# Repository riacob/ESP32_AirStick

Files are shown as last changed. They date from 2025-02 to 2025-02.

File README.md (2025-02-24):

# ESP32 AirStick
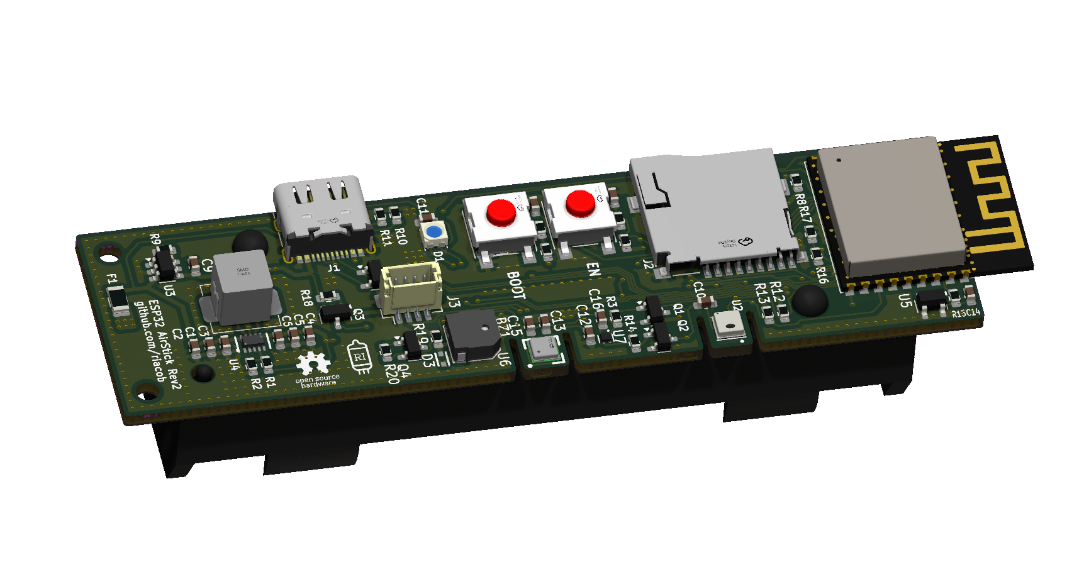
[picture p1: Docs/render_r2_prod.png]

The board is currently in Rev2

## Features
- AHT20 Temperature & Humidity Sensor
- ENS160 eCO2, AQI, TVOCs Sensor
- Measured TVOCs and their range:
  - Ethanol 0-6 ppm
  - Hydrogen 0-10 ppm
  - Acetone 0-32 ppm
  - Carbon Monoxide 0-90 ppm
  - Toluene 0-32 ppm
- 18650 Li-ion battery holder, TP4057 charging circuitry
- Battery protection with fuse and DW03
- USB Type-C with USB CDC for emulated UART and charging, ESD protected
- MicroSD TF card slot for data logging
- ESP32C3 For WiFi and BLE connectivity
- Still work in progress, compatible with [BLEMQTTPair]() app
- WS2812B led for indication and alarm
- Optional SSD1306 OLED 
- 75dB magnetic buzzer for alarm
- SparkFun Qwiic connector, in JST-SH 1.0mm pitch connector
- Optional connector to bring the rst and boot buttons to a remote front panel
- Low power, long life, high efficiency circuitry for optimized battery use
- Low BOM cost, consolidated parts, robust layout

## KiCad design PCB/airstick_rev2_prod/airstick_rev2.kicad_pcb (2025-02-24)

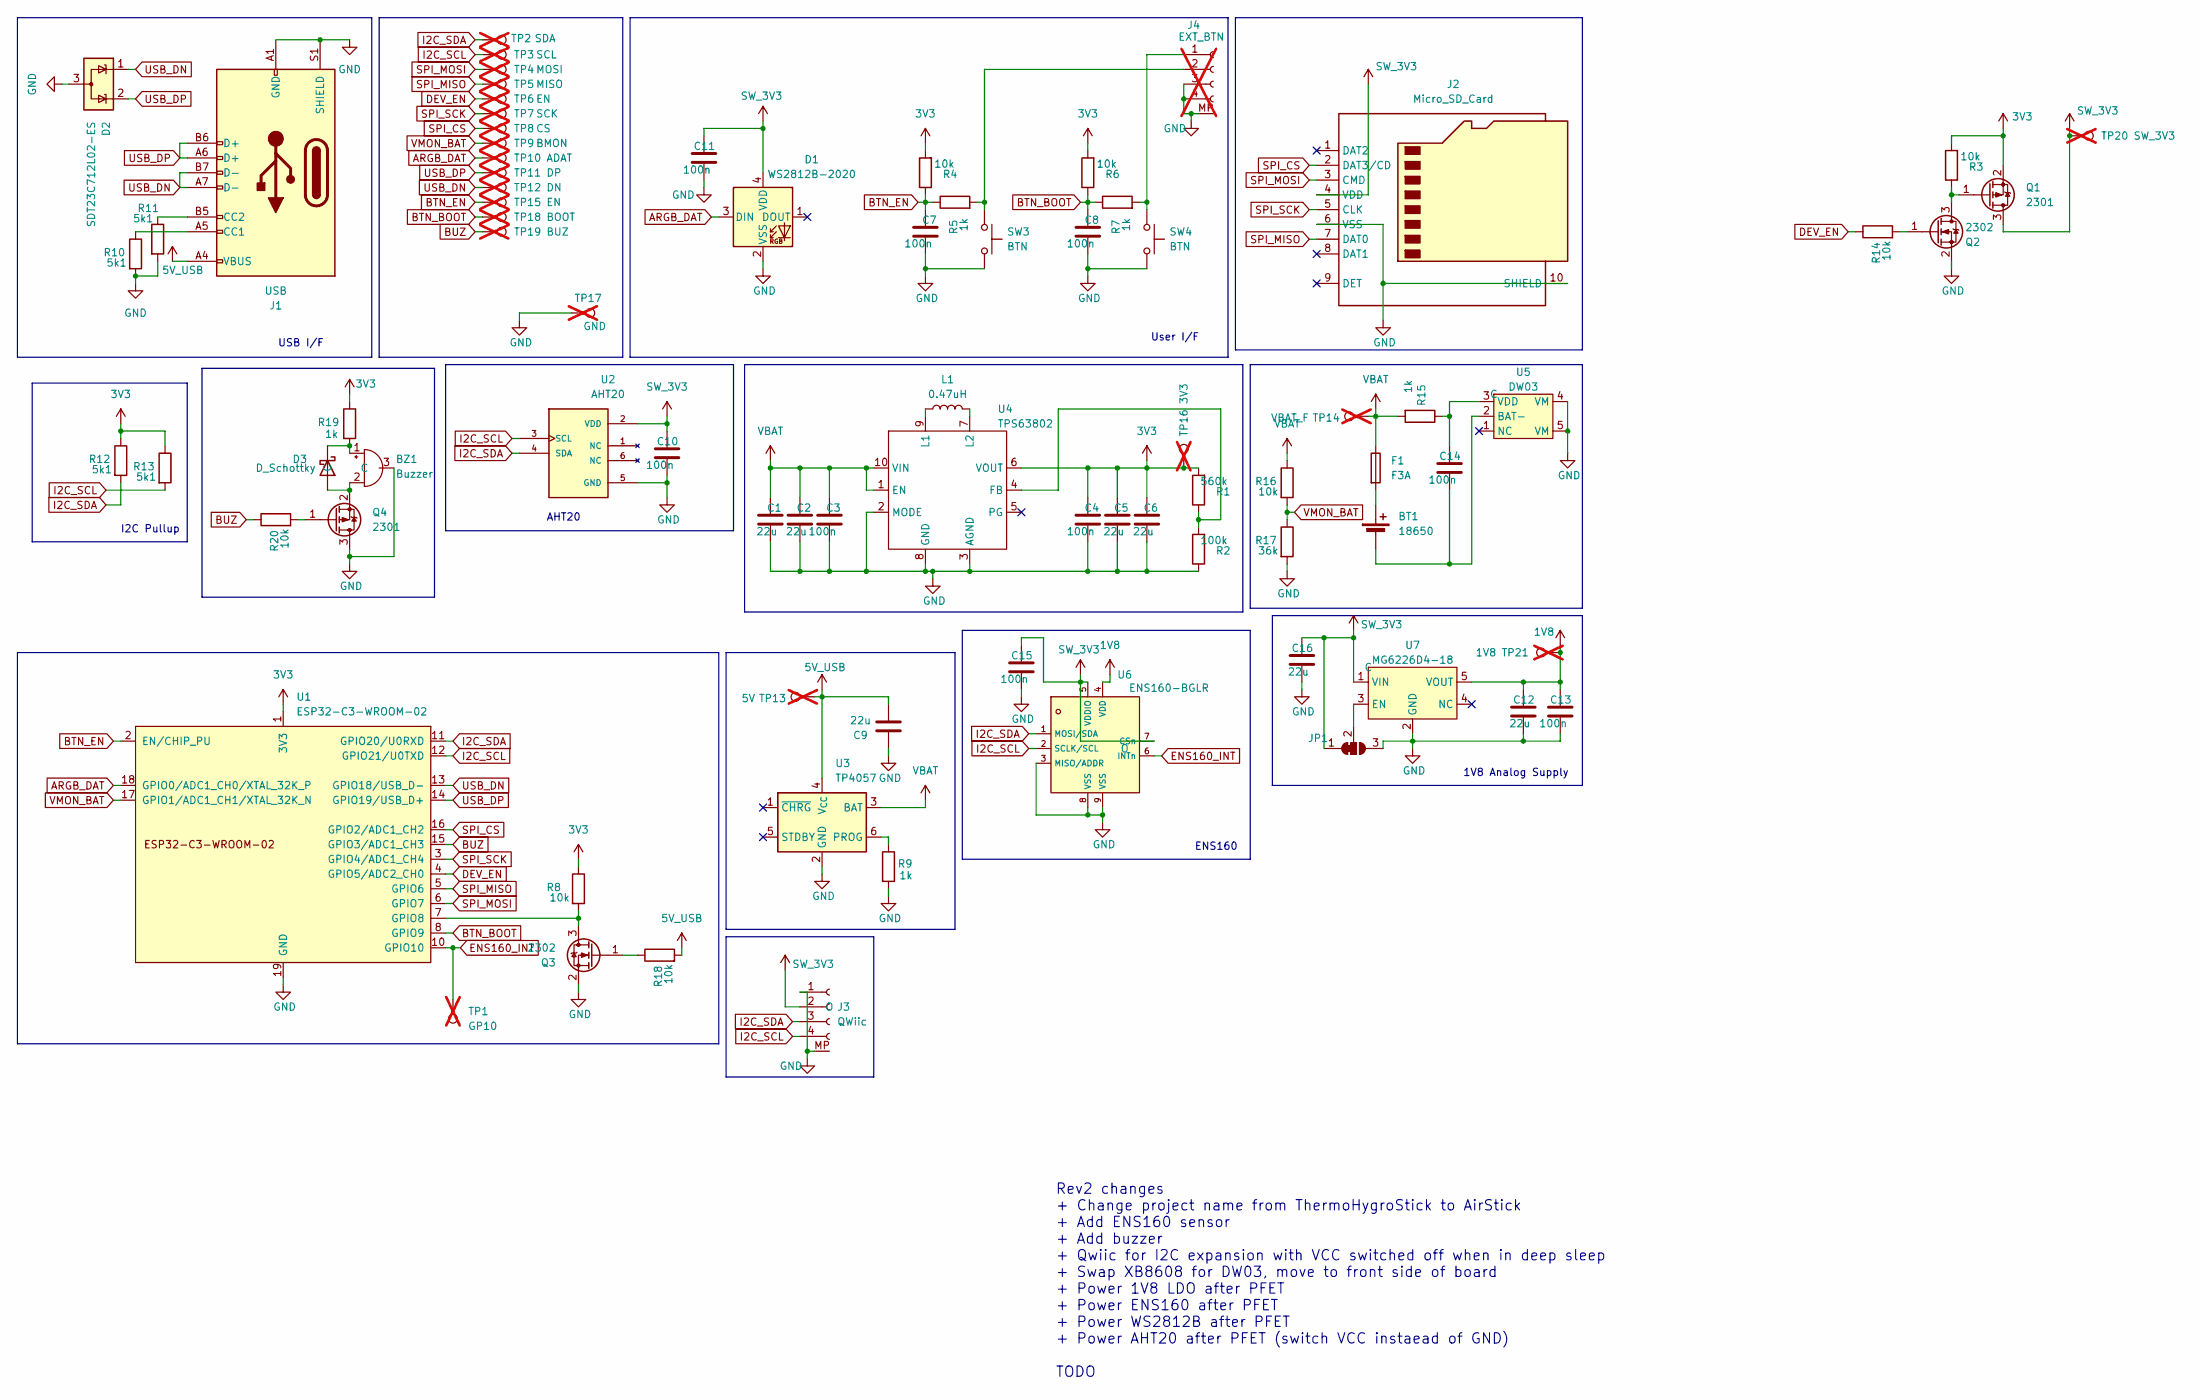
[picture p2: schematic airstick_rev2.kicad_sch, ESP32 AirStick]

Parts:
BT1: 18650; BatteryHolder_Keystone_1042_1x18650; LCSC C2988620
BZ1: Buzzer; BUZ-SMD_FST-5020; LCSC C391029
C1, C2, C5, C6, C9, C12, C16: 22u; C_0603_1608Metric; LCSC C159801
C3, C4, C7, C8, C10, C11, C13, C14, C15: 100n; C_0603_1608Metric; LCSC C1729
D1: WS2812B-2020; LED_WS2812B-2020_PLCC4_2.0x2.0mm; LCSC C5349955
D2: SDT23C712L02-ES; SOT-23-3; LCSC C5180269
D3: D_Schottky; SOD-723_L1.7-W1.0-P1.42-RD; LCSC C8525
F1: F3A; Fuse_1206_3216Metric; LCSC C163126
J1: USB; USB_C_Receptacle_G-Switch_GT-USB-7010ASV; LCSC C2988369
J2: Micro_SD_Card; J_SD_Card-micro_socket_A; LCSC C2988369
J3: QWiic; JST_SH_BM04B-SRSS-TB_1x04-1MP_P1.00mm_Vertical
J4: EXT_BTN; JST_SH_BM04B-SRSS-TB_1x04-1MP_P1.00mm_Vertical; not fitted
JP1: SolderJumper_3_Bridged12; SolderJumper-3_P1.3mm_Bridged12_RoundedPad1.0x1.5mm
L1: 0.47uH; L_SMD_7.1x6.6mm; LCSC C22463816
Q1, Q4: 2301; SOT-23; LCSC C41384537
Q2, Q3: 2302; SOT-23; LCSC C41384540
R1: 560k; R_0603_1608Metric; LCSC C17414
R2: 100k; R_0603_1608Metric; LCSC C17414
R3, R4, R6, R8, R14, R16, R18, R20: 10k; R_0603_1608Metric; LCSC C17414
R5, R7, R9, R15, R19: 1k; R_0603_1608Metric; LCSC C17414
R10, R11, R12, R13: 5k1; R_0603_1608Metric; LCSC C17414
R17: 36k; R_0603_1608Metric; LCSC C17414
SW3, SW4: BTN; SW_Push_1P1T_NO_6x6mm_H9.5mm; LCSC C2888455
TP1: GP10; TestPoint_Pad_D1.0mm_NoSilk; not fitted
TP2: SDA; TestPoint_Pad_D1.0mm_NoSilk; not fitted
TP3: SCL; TestPoint_Pad_D1.0mm_NoSilk; not fitted
TP4: MOSI; TestPoint_Pad_D1.0mm_NoSilk; not fitted
TP5: MISO; TestPoint_Pad_D1.0mm_NoSilk; not fitted
TP6, TP15: EN; TestPoint_Pad_D1.0mm_NoSilk; not fitted
TP7: SCK; TestPoint_Pad_D1.0mm_NoSilk; not fitted
TP8: CS; TestPoint_Pad_D1.0mm_NoSilk; not fitted
TP9: BMON; TestPoint_Pad_D1.0mm_NoSilk; not fitted
TP10: ADAT; TestPoint_Pad_D1.0mm_NoSilk; not fitted
TP11: DP; TestPoint_Pad_D1.0mm_NoSilk; not fitted
TP12: DN; TestPoint_Pad_D1.0mm_NoSilk; not fitted
TP13: 5V; TestPoint_Pad_D1.0mm_NoSilk; not fitted
TP14: VBAT_F; TestPoint_Pad_D1.0mm_NoSilk; not fitted
TP16: 3V3; TestPoint_Pad_D1.0mm_NoSilk; not fitted
TP17: GND; TestPoint_Pad_4.0x4.0mm; not fitted
TP18: BOOT; TestPoint_Pad_D1.0mm_NoSilk; not fitted
TP19: BUZ; TestPoint_Pad_D1.0mm_NoSilk; not fitted
TP20: SW_3V3; TestPoint_Pad_D1.0mm_NoSilk; not fitted
TP21: 1V8; TestPoint_Pad_D1.0mm_NoSilk; not fitted
U1: ESP32-C3-WROOM-02; LCSC C2934560
U2: AHT20; PSON100P300X300X110-6N; PARTREV V1.0; LCSC C2757850
U3: TP4057; SOT-23-6; LCSC C20199358
U4: TPS63802; DLA0010A; LCSC C1849531
U5: DW03; SOT-23-5
U6: ENS160-BGLR; LGA-9_L3.0-W3.0-R3-C3-P1.05-TL; LCSC C3659351
U7: MG6226D4-18; Texas_X2SON-4_1x1mm_P0.65mm; LCSC C22396246

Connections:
1V8: C12.1, C13.1, TP21.1, U6.4 (VDD), U7.5 (VOUT)
3V3: C4.1, C5.1, C6.1, Q1.2 (S), R1.2, R3.2, R4.2, R6.2, R8.1, R12.1, R13.1, R19.1, TP16.1, U1.1 (3V3), U4.6 (VOUT)
5V_USB: C9.2, J1.A4 (VBUS), J1.A9 (VBUS), J1.B4 (VBUS), J1.B9 (VBUS), R18.2, TP13.1, U3.4 (V_{CC})
ARGB_DAT: D1.3 (DIN), TP10.1, U1.18 (GPIO0/ADC1_CH0/XTAL_32K_P)
BTN_BOOT: C8.1, R6.1, R7.1, TP18.1, U1.8 (GPIO9)
BTN_EN: C7.1, R4.1, R5.1, TP15.1, U1.2 (EN/CHIP_PU)
BUZ: R20.1, TP19.1, U1.15 (GPIO3/ADC1_CH3)
DEV_EN: R14.1, TP6.1, U1.4 (GPIO5/ADC2_CH0)
ENS160_INT: TP1.1, U1.10 (GPIO10), U6.6 (INTn)
GND: BZ1.3 (-), C1.2, C2.2, C3.2, C4.2, C5.2, C6.2, C7.2, C8.2, C9.1, C10.2, C11.2, C12.2, C13.2, C15.2, C16.2, D1.2 (VSS), D2.3 (A), J1.A1 (GND), J1.A12 (GND), J1.B1 (GND), J1.B12 (GND), J1.S1 (SHIELD), J2.6 (VSS), J2.10 (SHIELD), J3.1, J3.MP, J4.3, J4.4, J4.MP, JP1.3 (B), Q2.2 (S), Q3.2 (S), Q4.3 (D), R2.1, R9.2, R10.2, R11.2, R17.2, SW3.2, SW4.2, TP17.1, U1.9 (GND), U1.19 (GND), U2.5 (GND), U3.2 (GND), U4.2 (MODE), U4.3 (AGND), U4.8 (GND), U5.4 (VM), U5.5 (VM), U6.3 (MISO/ADDR), U6.8 (VSS), U6.9 (VSS), U7.2 (GND)
I2C_SCL: J3.4, R13.2, TP3.1, U1.12 (GPIO21/U0TXD), U2.3 (SCL), U6.2 (SCLK/SCL)
I2C_SDA: J3.3, R12.2, TP2.1, U1.11 (GPIO20/U0RXD), U2.4 (SDA), U6.1 (MOSI/SDA)
unnamed: BT1.1 (+), F1.2
unnamed: BT1.2 (-), C14.2, U5.2 (BAT-)
unnamed: BZ1.1 (+), D3.1 (K), R19.2
unnamed: BZ1.2 (-), D3.2 (A), Q4.2 (S)
unnamed: J1.A5 (CC1), R10.1
unnamed: J1.B5 (CC2), R11.1
unnamed: J4.1, R7.2, SW4.1
unnamed: J4.2, R5.2, SW3.1
unnamed: JP1.2 (C), U7.3 (EN)
unnamed: Q1.1 (G), Q2.3 (D), R3.1
unnamed: Q2.1 (G), R14.2
unnamed: Q3.3 (D), R8.2, U1.7 (GPIO8)
unnamed: Q3.1 (G), R18.1
unnamed: Q4.1 (G), R20.2
unnamed: R9.1, U3.6 (PROG)
unnamed: R1.1, R2.2, U4.4 (FB)
unnamed: L1.1, U4.9 (L1)
unnamed: L1.2, U4.7 (L2)
unnamed: C14.1, R15.1, U5.3 (VDD)
SPI_CS: J2.2 (DAT3/CD), TP8.1, U1.16 (GPIO2/ADC1_CH2)
SPI_MISO: J2.7 (DAT0), TP5.1, U1.5 (GPIO6)
SPI_MOSI: J2.3 (CMD), TP4.1, U1.6 (GPIO7)
SPI_SCK: J2.5 (CLK), TP7.1, U1.3 (GPIO4/ADC1_CH4)
SW_3V3: C10.1, C11.1, C15.1, C16.1, D1.4 (VDD), J2.4 (VDD), J3.2, JP1.1 (A), Q1.3 (D), TP20.1, U2.2 (VDD), U6.5 (VDDIO), U6.7 (CSn), U7.1 (VIN)
USB_DN: D2.1 (K), J1.A7 (D-), J1.B7 (D-), TP12.1, U1.13 (GPIO18/USB_D-)
USB_DP: D2.2 (K), J1.A6 (D+), J1.B6 (D+), TP11.1, U1.14 (GPIO19/USB_D+)
VBAT: C1.1, C2.1, C3.1, F1.1, R15.2, R16.1, TP14.1, U3.3 (BAT), U4.1 (EN), U4.10 (VIN)
VMON_BAT: R16.2, R17.1, TP9.1, U1.17 (GPIO1/ADC1_CH1/XTAL_32K_N)

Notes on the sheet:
1V8 Analog Supply
Rev2 changes + Change project name from ThermoHygroStick to AirStick + Add ENS160 sensor + Add buzzer + Qwiic for I2C expansion with VCC switched off when in deep sleep + Swap XB8608 for DW03, move to front side of board + Power 1V8 LDO after PFET + Power ENS160 after PFET + Power WS2812B after PFE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
AHT20
I2C Pullup
USB I/F
User I/F
ENS160

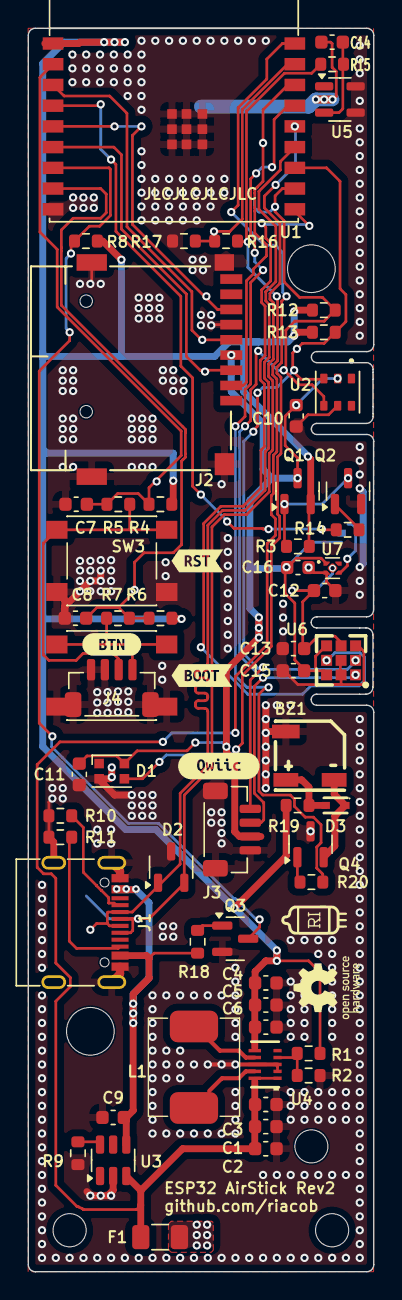
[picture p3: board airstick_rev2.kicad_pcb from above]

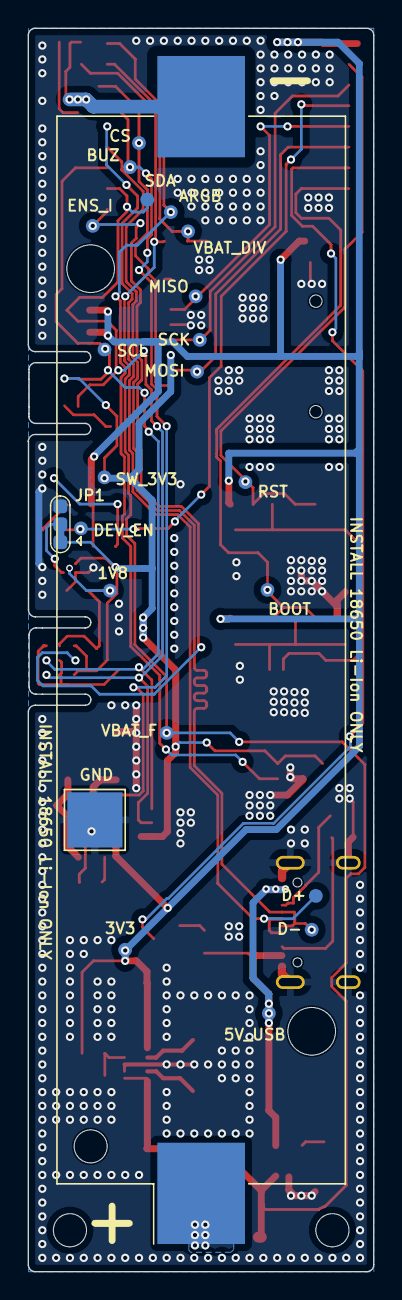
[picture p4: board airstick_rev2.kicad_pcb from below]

Board: 2 copper layers, 25.0 x 90.0 mm, 86 parts (23 on the bottom side), 40 nets.

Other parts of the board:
kibuzzard-67BA5A9B: G***; kibuzzard-67BA5A9B
kibuzzard-67BA57D8: G***; kibuzzard-67BA57D8
kibuzzard-67BA587D: G***; kibuzzard-67BA587D
kibuzzard-67BA5873: G***; kibuzzard-67BA5873

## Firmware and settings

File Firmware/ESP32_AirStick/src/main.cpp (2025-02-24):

/**
 * @file main.cpp
 * @author Riccardo Iacob (github.com/riacob)
 * @brief ThermoHygroStick entry point and related functions
 * @version 0.1
 * @date 2025-01-26
 *
 * @copyright Copyright (c) 2025
 *
 */
#include <Arduino.h>
#define LOG_LOCAL_LEVEL ESP_LOG_VERBOSE
#include <Wire.h>
#include <esp_log.h>

#include "Fonts/FreeMono12pt7b.h"
#include "aht20.h"
#include "config.h"
#include "mqtt.h"
#include "mqtt_cfg.h"
#include "ssd1306.h"


#define PIN_SDA     20
#define PIN_SCL     21
#define PIN_PWR     5
#define SERIAL_BAUD 115200

GlobalConfig cfg;
AHT20 aht(&Wire);
MQTT mqtt(&cfg);
SSD1306 oled(&Wire);

String TOPIC_DISCOVERY_TEMPERATURE, PAYLOAD_DISCOVERY_TEMPERATURE, TOPIC_DISCOVERY_HUMIDITY, PAYLOAD_DISCOVERY_HUMIDITY, TOPIC_TEMPERATURE, TOPIC_HUMIDITY;

String genDiscoveryTopicTemperature();
String genDiscoveryTopicHumidity();
String genTopicTemperature();
String genTopicHumidity();
String genDiscoveryPayloadTemperature();
String genDiscoveryPayloadHumidity();

void setup() {
  pinMode(PIN_PWR, OUTPUT);
  digitalWrite(PIN_PWR, HIGH);
  Serial.println("pwr pin init");

  Serial.begin(SERIAL_BAUD);
  Serial.println("serial init");
  Wire.begin(PIN_SDA, PIN_SCL, 100000);
  Serial.println("i2c init");
  aht.init();
  Serial.println("aht20 init");
  oled.init();
  Serial.println("oled init");
  mqtt.init();
  Serial.println("mqtt init");

  TOPIC_DISCOVERY_TEMPERATURE = genDiscoveryTopicTemperature();
  PAYLOAD_DISCOVERY_TEMPERATURE = genDiscoveryPayloadTemperature();
  TOPIC_DISCOVERY_HUMIDITY = genDiscoveryPayloadHumidity();
  PAYLOAD_DISCOVERY_HUMIDITY = genDiscoveryPayloadHumidity();
  TOPIC_TEMPERATURE = genTopicTemperature();
  TOPIC_HUMIDITY = genTopicHumidity();
  Serial.println("mqtt params init");

  ///* Publish MQTT discovery */
  //mqtt.runLoop();
  //// Discovery for temperature sensor
  //mqtt.pubsubClient->publish(TOPIC_DISCOVERY_TEMPERATURE.c_str(), PAYLOAD_DISCOVERY_TEMPERATURE.c_str());
  //// Discovery for humidity sensor
  //mqtt.pubsubClient->publish(TOPIC_DISCOVERY_HUMIDITY.c_str(), PAYLOAD_DISCOVERY_HUMIDITY.c_str());
  //Serial.println("mqtt discovery init");
}

void loop() {
  /* Read sensor */
  //mqtt.runLoop();
  if (!aht.read()) {
    /* Publish readings to MQTT */
    String temp = String(aht.getCelsius());
    String rh = String(aht.getHumidity());
    oled._ssd1306->clearDisplay();
    //oled._ssd1306->setFont(&FreeMono12pt7b);
    oled._ssd1306->setCursor(4, 4);
    oled._ssd1306->print(temp);
    oled._ssd1306->println(" C");
    oled._ssd1306->print(rh);
    oled._ssd1306->println(" %");
    oled._ssd1306->display();
    //mqtt.pubsubClient->publish(TOPIC_TEMPERATURE.c_str(), temp.c_str());
    //mqtt.pubsubClient->publish(TOPIC_HUMIDITY.c_str(), rh.c_str());
    //Serial.println("Data published to MQTT");
  }
  /* Wait 5 seconds */
  delay(5000);
}

String genDiscoveryTopicTemperature() {
  String clientId = "ESP32-THS-";
  clientId += String(WiFi.macAddress());
  return String("homeassistant/sensor/" + clientId + "_temperature/config");
}

String genDiscoveryTopicHumidity() {
  String clientId = "ESP32-THS-";
  clientId += String(WiFi.macAddress());
  return String("homeassistant/sensor/" + clientId + "_humidity/config");
}

String genDiscoveryPayloadTemperature() {
  String clientId = "ESP32-THS-";
  clientId += String(WiFi.macAddress());
  return String("{\"name\":\"ESP32 Temperature\",\"state_topic\":\"homeassistant/sensor/" + clientId + "_temperature/state\",\"unit_of_measurement\":\"°C\",\"device_class\": \"temperature\"}");
}

String genDiscoveryPayloadHumidity() {
  String clientId = "ESP32-THS-";
  clientId += String(WiFi.macAddress());
  return String("{\"name\":\"ESP32 Humidity\",\"state_topic\":\"homeassistant/sensor/" + clientId + "_humidity/state\",\"unit_of_measurement\":\"%\",\"device_class\": \"humidity\"}");
}

String genTopicTemperature() {
  String clientId = "ESP32-THS-";
  clientId += String(WiFi.macAddress());
  return String("homeassistant/sensor/" + clientId + "_temperature/state");
}

String genTopicHumidity() {
  String clientId = "ESP32-THS-";
  clientId += String(WiFi.macAddress());
  return String("homeassistant/sensor/" + clientId + "_humidity/state");
}

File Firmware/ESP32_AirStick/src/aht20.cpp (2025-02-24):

/**
 * @file aht20.cpp
 * @author Riccardo Iacob (github.com/riacob)
 * @brief Implementation file for aht20.h library
 * @version 0.1
 * @date 2025-01-26
 *
 * @copyright Copyright (c) 2025
 *
 */
#include "aht20.h"

#define AHT_ADD              0x38       /* 7-bit address */
#define AHT_CMD_INIT         0b10111110 /* Initialization command */
#define AHT_CMD_INIT_PAR0    0x08       /* Initialization command first parameter */
#define AHT_CMD_INIT_PAR1    0x00       /* Initialization command second parameter */
#define AHT_CMD_TRIGGER      0xAC       /* Trigger measurement command */
#define AHT_CMD_TRIGGER_PAR0 0x33       /* Trigger command first parameter */
#define AHT_CMD_TRIGGER_PAR1 0x00       /* Trigger command second parameter */
#define AHT_CMD_RST          0b10111010 /* Soft reset command */
#define AHT_MASK_BUSY        0b00000001 /* Mask for busy flag in status byte */
#define AHT_MASK_CAL         0b00010000 /* Mask for incal flag in status byte */
#define AHT_MASK_RH          0xFFFFF000 /* Mask for clearing extra humidity bits */
#define AHT_MASK_TEMP        0x000FFFFF /* Mask for clearing extra temperature bits */

AHT20::AHT20(TwoWire *twi) {
  _wire = twi;
}

void AHT20::init() {
  uint8_t status;
  /* Read status byte */
  _wire->requestFrom(AHT_ADD, 1);
  while (_wire->available() < 1) {
    delay(5);
  }
  status = _wire->read();
  /* Check whether calbibration bit is set */
  if (!(status & AHT_MASK_CAL)) {
    Serial.println("[Init] Calibration bit not set, calibrating...");
    /* If not, we need to initialize calibration */
    _wire->beginTransmission(AHT_ADD);
    _wire->write(AHT_CMD_INIT);
    _wire->write(AHT_CMD_INIT_PAR0);
    _wire->write(AHT_CMD_INIT_PAR1);
    _wire->endTransmission();
    Serial.println("[Init] Calibration complete!");
    /* Wait for 10mS after calibration */
    delay(10);
  }
  Serial.println("[Init] Calibration bit is set");
}

uint8_t AHT20::read() {
  uint8_t buf[7];
  uint32_t raw_temp, raw_rh;
  /* Trigger measurement */
  _wire->beginTransmission(AHT_ADD);
  _wire->write(AHT_CMD_TRIGGER);
  _wire->write(AHT_CMD_TRIGGER_PAR0);
  _wire->write(AHT_CMD_TRIGGER_PAR1);
  _wire->endTransmission();
  /* Wait for 80mS after triggering measurement */
  delay(80);
  /* Read data */
  _wire->requestFrom(AHT_ADD, 7);
  while (_wire->available() < 7) {
    Serial.print("[Read] Data bytes available: ");
    Serial.println(_wire->available());
    delay(5);
  }
  for (int i = 0; i < 7; i++) {
    buf[i] = _wire->read();
  }
  /* If the busy flag is set, the measurement is invalid */
  if (!(buf[1] & AHT_MASK_BUSY)) {
    Serial.println("[Read] ERROR: DEVICE BUSY");
    return AHT_ERR_BUSY;
  }
  /* Set last read millis */
  _lastReadMillis = millis();
  /* Parse humidity (20 bit) */
  raw_rh = 0;
  raw_rh = buf[1];
  raw_rh = (raw_rh << 8);
  raw_rh |= buf[2];
  raw_rh = (raw_rh << 8);
  raw_rh |= buf[3];
  raw_rh &= AHT_MASK_RH;
  raw_rh = (raw_rh >> 4);
  _rh = (((float)raw_rh / 1048576.0) * 100.0);  // 1048576 = 2^20 (the raw range)
  /* Parse temperature (20-bit) */
  raw_temp = 0;
  raw_temp = buf[3];
  raw_temp = (raw_temp << 8);
  raw_temp |= buf[4];
  raw_temp = (raw_temp << 8);
  raw_temp |= buf[5];
  raw_temp &= AHT_MASK_TEMP;
  _temp = ((((float)raw_temp / 1048576.0) * 200.0) - 50.0);  // 1048576 = 2^20 (the raw range)
  /* Log */
  Serial.print("[Read] Temperature: ");
  Serial.print(_temp);
  Serial.print("C, Humidity: ");
  Serial.print(_rh);
  Serial.println("%");
  return AHT_ERR_NONE;
}

float AHT20::getCelsius() {
  return _temp;
}

float AHT20::getHumidity() {
  return _rh;
}
